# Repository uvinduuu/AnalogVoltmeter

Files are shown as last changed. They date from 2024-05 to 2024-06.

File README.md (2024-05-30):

# Analog Voltmeter Project

## Overview

This repository contains the details and design files for the Analog Voltmeter project developed by Group 06 at the Department of Electronic & Telecommunication Engineering, University of Moratuwa, Sri Lanka. The project was completed in partial fulfillment of the requirements for the module EN 2091 Laboratory Practice and Projects.

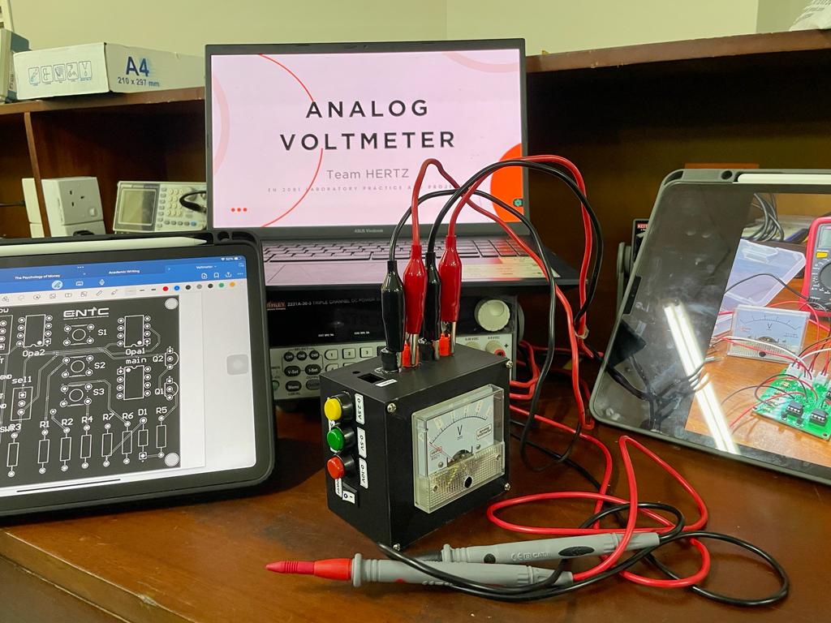
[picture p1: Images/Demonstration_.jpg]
Final Demonstration


## Group Members

- Sehara G.M.M.
- Kodikara U.S.S.
- Pathirana R.P.S.
- Gunawardhana E.R.N.H.

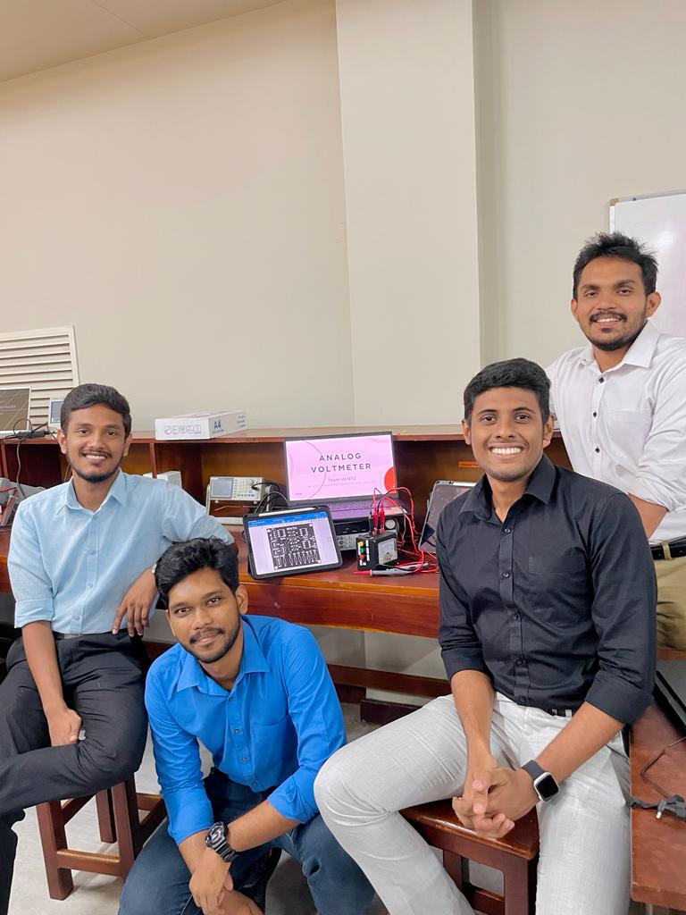
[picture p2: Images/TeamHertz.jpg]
Team


## Project Abstract

The analog voltmeter is designed to measure voltage levels in electronic circuits across three ranges: 0-2.5V, 0-5V, and 0-10V. The device uses precision analog components like resistors, capacitors, and operational amplifiers to ensure accurate voltage measurements. The design, simulation, and optimization are carried out using NI Multisim 14.2, SolidWorks for enclosure design, and Altium for PCB design.

## Contents

1. [Introduction and Functionality](#introduction-and-functionality)
2. [System Architecture](#system-architecture)
   - [Functional Block Diagram](#functional-block-diagram)
   - [Maintaining a high Input Impedance](#maintaining-a-high-input-impedance)
   - [Overload Protection](#overload-protection)
   - [Measurement Range](#measurement-range)
   - [Analog Display Customization](#analog-display-customization)
   - [Power Supply](#power-supply)
3. [Component Selection](#component-selection)
4. [PCB Design](#pcb-design)
5. [Enclosure Design](#enclosure-design)
6. [Software Simulation and Hardware Testing](#software-simulation-and-hardware-testing)
7. [Conclusion & Future Works](#conclusion--future-works)
8. [Bill of Materials](#bill-of-materials)
9. [References](#references)

## Introduction and Functionality

The primary objective is to design a high-precision voltmeter that provides accurate voltage measurements while imposing minimal impact on the circuit under test. Unlike traditional voltmeters, our project incorporates operational amplifiers (Op-Amps) to achieve high input impedance and effectively isolate the voltmeter circuit from the measured circuit.

## System Architecture

### Functional Block Diagram

The system comprises four main blocks: input, output, power supply, and amplifier. The amplifier block consists of the main amplifier and the overload protection circuit.

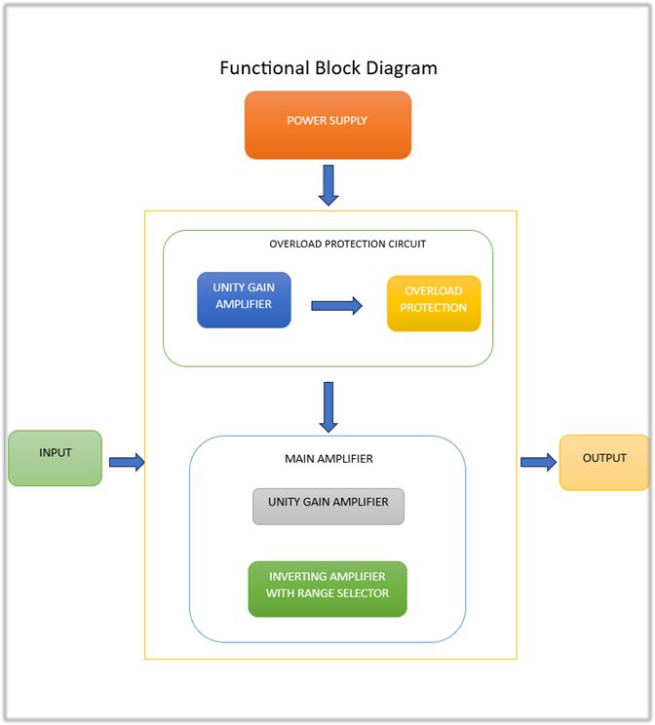
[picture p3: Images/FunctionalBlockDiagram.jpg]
Functional Block Diagram


### Maintaining a high Input Impedance

A unity gain amplifier circuit utilizing the LM358 operational amplifier is used to maintain high input impedance, ensuring accurate voltage readings.

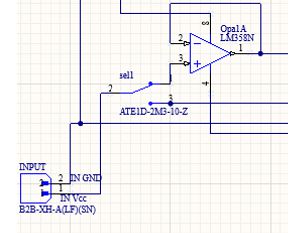
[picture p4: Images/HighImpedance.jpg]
Unity gain amplifier


### Overload Protection

An effective overload protection system using BC558 PNP transistors and a 16-volt Zener diode is implemented to protect the voltmeter from potential overload scenarios.

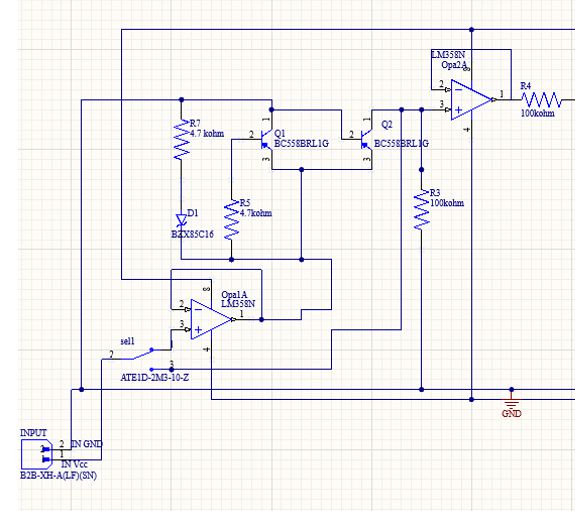
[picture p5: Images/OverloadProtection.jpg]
Overload Protection


### Measurement Range

The voltmeter can measure across three distinct ranges: 0-2.5V, 0-5V, and 0-10V, with the flexibility to select the desired range using push buttons.

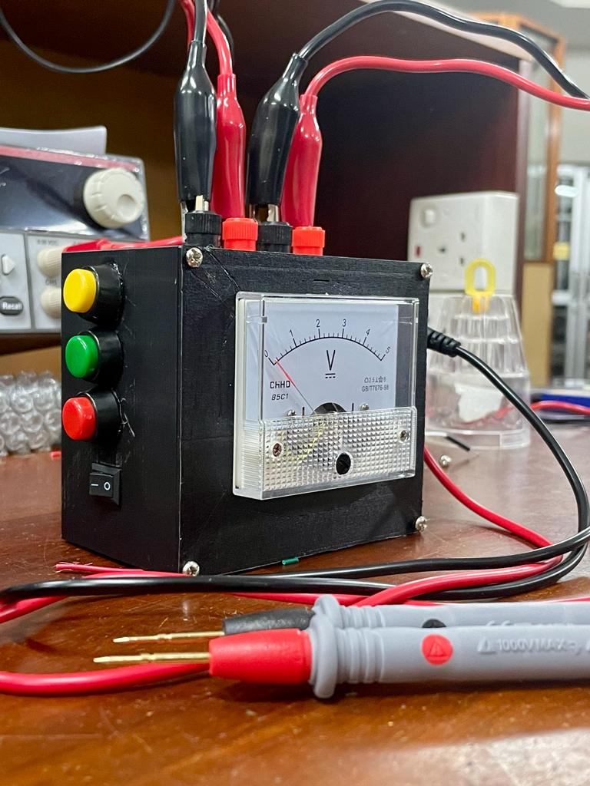
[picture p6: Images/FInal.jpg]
Final Product


### Analog Display Customization

A customized analog display featuring an analog needle is implemented for voltage measurement across three distinct ranges.

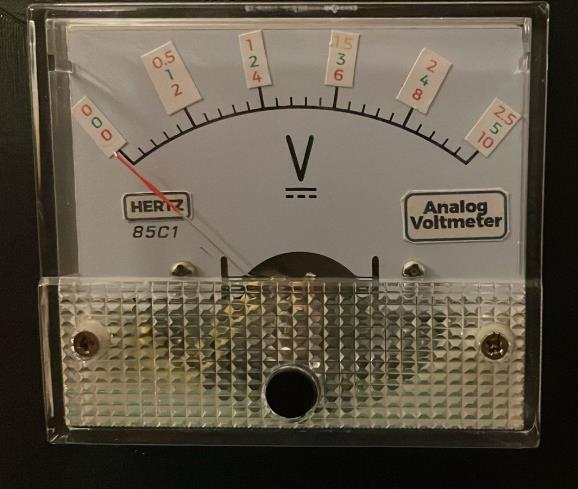
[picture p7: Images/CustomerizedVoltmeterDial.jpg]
Analog Display


### Power Supply

A dedicated power supply circuit transforms the incoming 230V AC voltage into a consistent +12V and -12V DC supply for the operational amplifiers.

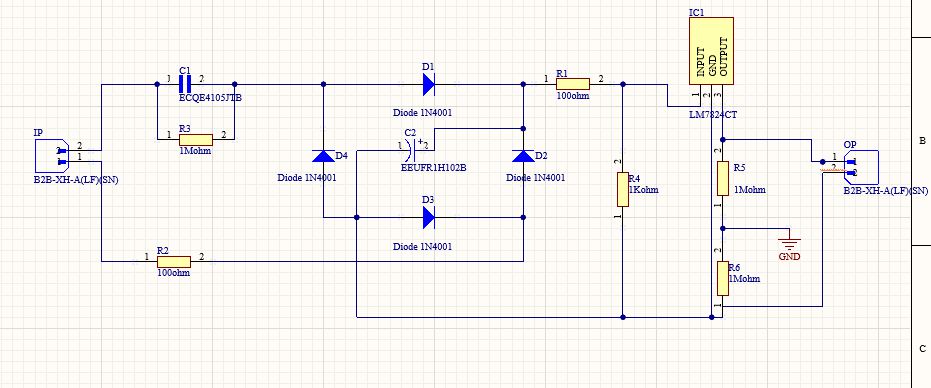
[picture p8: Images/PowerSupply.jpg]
PowerSupply


## Component Selection

- **Overload Protection**: BC558B Transistor, LM358P Op-Amp, 16V Zener diode
- **Main Amplifying Circuit**: LM358P Op-Amp, Resistors (100Kohm, 50Kohm, 200Kohm), Voltmeter Panel
- **Power Supply Circuit**: IN4001 Diodes, Capacitors, LM7824 Voltage Regulator

## PCB Design

We have designed two PCBs for the voltmeter and the power supply circuit. The PCB is designed using Altium with a compact layout to optimize performance. Design files are available in the repository.

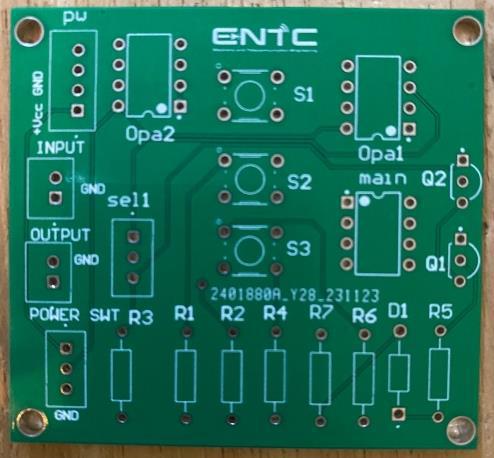
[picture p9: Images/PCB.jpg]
Voltmeter main PCB

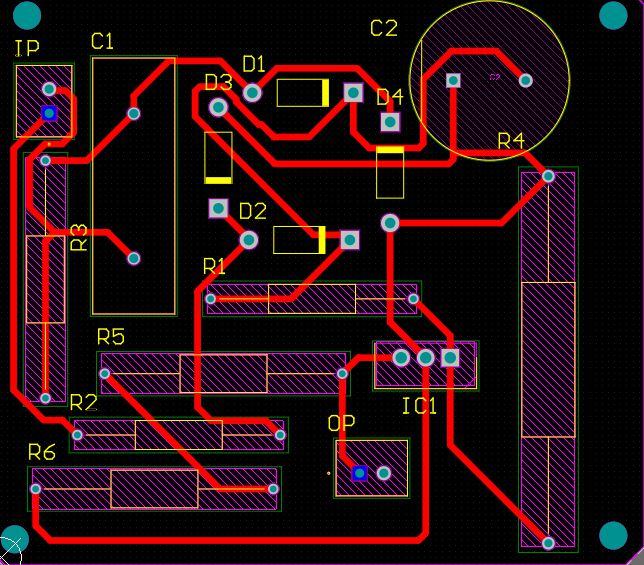
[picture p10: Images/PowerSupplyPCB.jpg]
Power Supply PCB


## Enclosure Design

The enclosure is designed using SolidWorks, ensuring user-friendly access and durability. Design files are available in the repository.

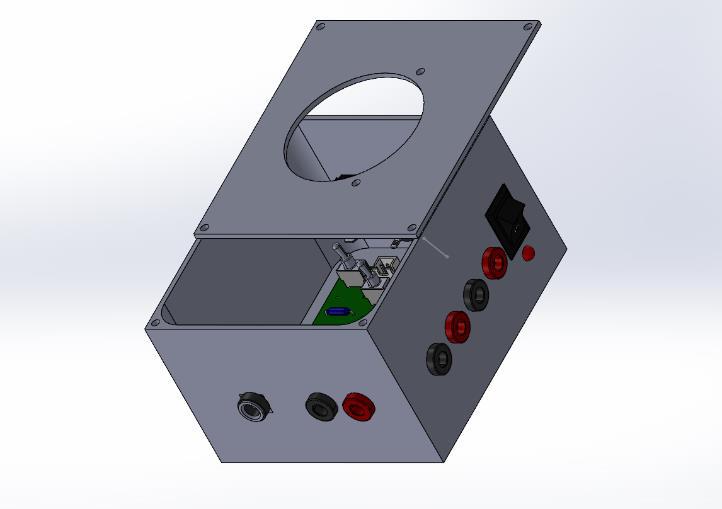
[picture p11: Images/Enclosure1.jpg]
Enclosure


## Software Simulation and Hardware Testing

Simulations were performed using Multisim software to validate the circuit design, followed by hardware implementation and testing to ensure accurate results.

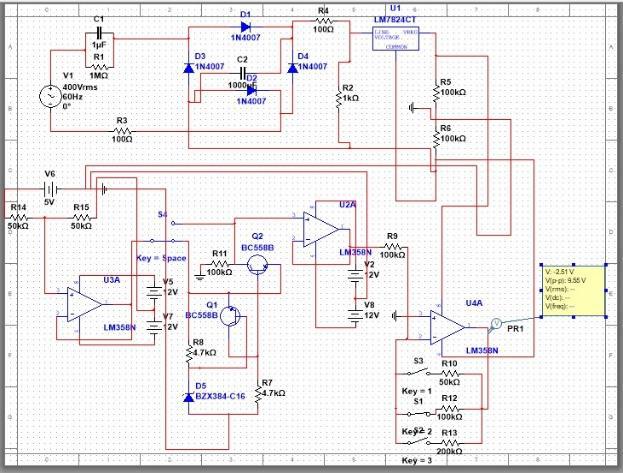
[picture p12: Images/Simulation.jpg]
Simulation

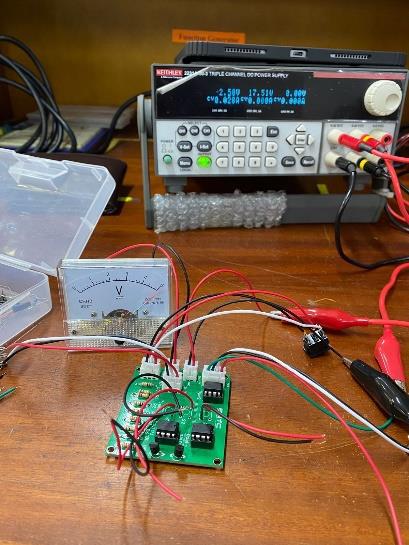
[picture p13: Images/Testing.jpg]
Testing

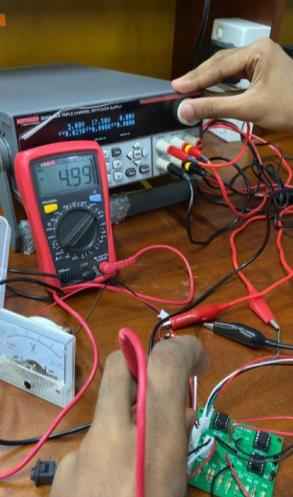
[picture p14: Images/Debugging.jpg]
Debugging


## Conclusion & Future Works

The project aims to provide a cost-effective and reliable analog voltmeter solution with emphasis on precision, durability, and ease of use. Future developments include PCB implementation for optimized power supply, boost converter integration, improved measurement parameters, and implementing a static calibration mechanism.

## Bill of Materials

| Component | Description | Quantity |
|---|---|---|
| BC558B Transistor | PNP Bipolar Junction Transistor | 2 |
| LM358P Op-Amp | Dual Operational Amplifier | 3 |
| 16V Zener Diode | Zener Diode for Voltage Regulation  | 1 |
| Resistor 100KΩ | Resistor | 2 |
| Resistor 50KΩ | Resistor | 1 |
| Resistor 200KΩ | Resistor | 1 |
| Voltmeter Panel | Analog Voltmeter Display | 1 |
| IN4001 Diode | General-Purpose Diode | 4 |
| Capacitors | Various values for filtering | Multiple |
| LM7824 Voltage Regulator| 24V Voltage Regulator | 1 |

---

A detailed bill of materials is provided in the report, listing all components used in the project.

## References

1. [Overvoltage Protection Circuit](https://circuitdigest.com/electronic-circuits/overvoltage-protection-circuit) (no date) Circuit Digest - Electronics Engineering News, Latest Products, Articles and Projects.
2. [Alldatasheet.com (no date) BC558 Datasheet(PDF) – semtech corporation](https://www.alldatasheet.com/datasheet-pdf/pdf/42388/SEMTECH/BC558.html), ALLDATASHEET.COM - Electronic Parts Datasheet Search.
3. [Alldatasheet.com (no date b) LM358 PDF, LM358 description, LM358 datasheet, LM358 View](https://pdf1.alldatasheet.com/datasheet-pdf/view/1648891/TI/LM358.html), ALLDATASHEET.
4. [Storr, W. (2022) Inverting operational amplifier - the inverting op-amp](https://www.electronics-tutorials.ws/opamp/opamp_2.html), Basic Electronics Tutorials.
5. [How to connect a PNP transistor in a circuit](https://www.learningaboutelectronics.com/Articles/How-to-connect-a-pnp-transistor-in-a-circuit.php) (No date).

---
## Contact

For any clarifications or inquiries please feel free to contact me at uvindukodikara@gmail.com

---

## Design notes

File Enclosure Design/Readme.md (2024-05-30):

# Enclosure Design for Analog Voltmeter Project

## Overview

We have designed a custom enclosure using SolidWorks for the analog voltmeter project. This enclosure is designed to house the circuit components and provide user-friendly access to connectors and controls.

### Enclosure Specifications

- **Dimensions**: The enclosure measures 10cm x 9cm.
- **User-Friendly Design**: Special attention was given to usability and accessibility during the design process.
- **Power Supply**: The enclosure includes:
  - 4 banana connectors for laboratory power supply connection.
  - 1 barrel jack connector for 24V power supply connection. Users can choose either power source.
- **Probe Connections**: Two banana connectors are provided for connecting the probes.
- **Switches**: The enclosure features:
  - A power switch.
  - A separate switch for enabling overload protection.
- **Push Buttons**: There are 3 push buttons for range selection.

## Enclosure Design

The enclosure is designed to ensure ease of use and protection for the circuit components. It provides clear access to connectors and switches, enhancing user interaction and functionality.

### SolidWorks Design

The enclosure was created using SolidWorks, focusing on precise dimensions and ergonomic usability. Detailed attention was given to integrate all necessary components effectively.

Enclosure Design
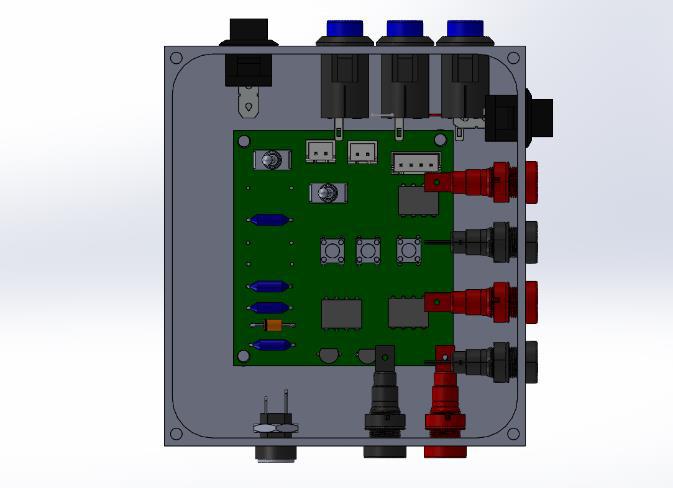
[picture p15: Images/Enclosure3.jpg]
Enclosure Design


*Figures : Enclosure design rendered using SolidWorks.*

## Future Developments

Future iterations of the enclosure may include enhancements for improved durability, aesthetics, and functionality based on user feedback and project requirements.

## Assembly Instructions

1. **Component Installation**: Carefully install the circuit components inside the enclosure.
2. **Connector Connections**: Connect the banana connectors and barrel jack as described.
3. **Switch and Button Placement**: Mount the power switch, overload protection switch, and range selection buttons in their designated positions.

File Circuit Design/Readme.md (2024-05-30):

### 1. Initial Circuit Sketch
- Create a detailed sketch of the circuit using LTSpice with the basic inverting and non inverting amplifiing circuits we learned in operational amplifier circuits. Then simulated them using NI Multisim.
- List all components and their connections as we have to select 3 ranges in the amplifier and the overload protection.

### 2. Circuit Simulation Using NI Multisim
- Model the circuit in NI Multisim.
- Conduct two separate simulations:
  - Voltmeter Simulation: Verify voltage measurement and calibration.
  - Power Supply Simulation: Verify stability and output characteristics.
- Combine simulations into a single setup to ensure compatibility and functionality.
  
Full Simulation

*Figure : Simulation with Power Supply*

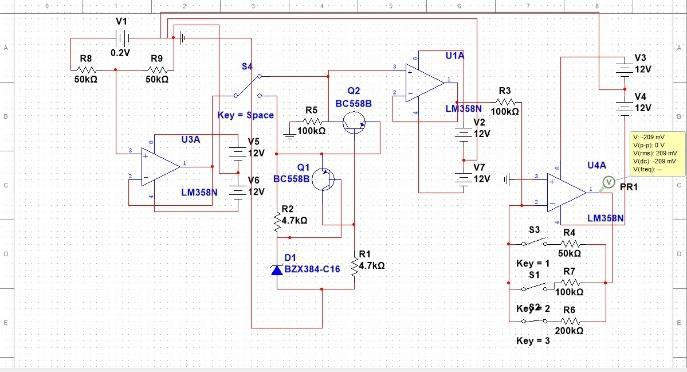
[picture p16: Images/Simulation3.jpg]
Simulation Range 1


*Figure : Simulation in 0-2.5V Range*

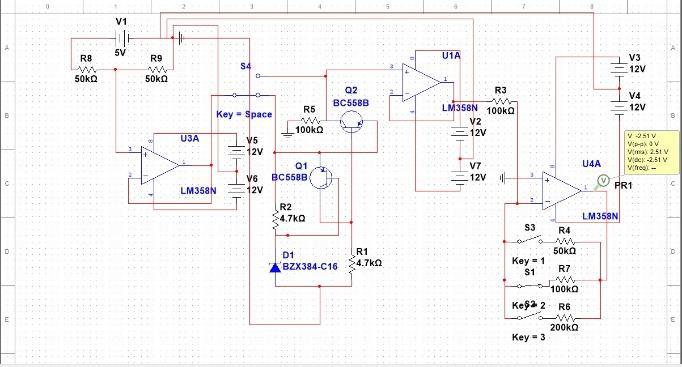
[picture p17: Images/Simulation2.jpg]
Simulation Range 2


*Figure : Simulation in 0-5V Range*

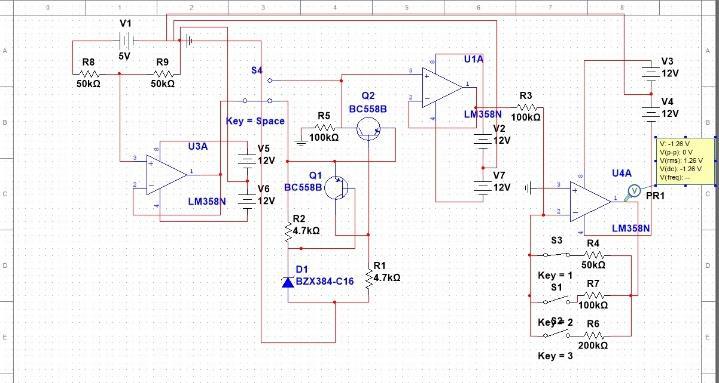
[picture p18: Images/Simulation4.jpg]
Simulation Range 3


*Figure : Simulation in 0-10V Range*

### 3. Prototyping on Breadboard
- Assemble the circuit on a breadboard.
- Debug and resolve any issues.
- Calibrate the circuit for optimal performance.

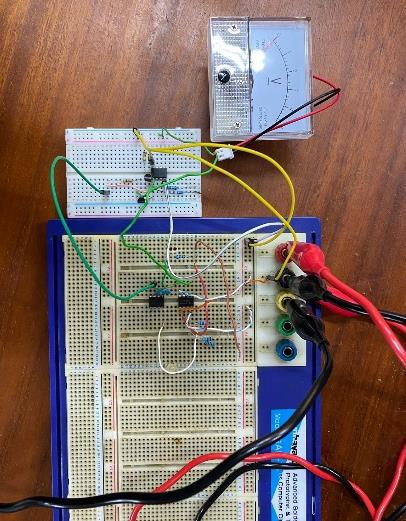
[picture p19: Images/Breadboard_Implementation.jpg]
Breadboard Implementation


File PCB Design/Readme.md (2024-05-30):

# PCB Overview

This project involves the design, construction, and testing of an analog voltmeter circuit along with its associated power supply. The circuit was initially prototyped on a breadboard, then implemented on custom PCBs. The power supply circuit is designed as a single-layer PCB, while the range amplifier PCB is a two-layer design.

## PCB Details

### Power Supply Circuit

- **PCB Configuration**: The power supply circuit is designed on a single-layer PCB.
- **Manufacturing Details**: The power supply PCB was manufactured locally in Sri Lanka, leveraging a domestic PCB printing shop.
- **Component Type**: All components used in the power supply circuit are through-hole components.

### Range Amplifier PCB

- **PCB Configuration**: The range amplifier PCB is designed on a two-layer PCB.
- **Manufacturing Details**: PCB was fabricated through JLCPCB, utilizing their online PCB manufacturing service.
- **Component Type**: All components used in the range amplifier circuit are through-hole components.

## Testing and Verification

The circuit was extensively simulated across different voltage ranges (0-2.5V, 0-5V, and 0-10V) to ensure functionality and accuracy. After successful soldering, the circuit was tested using an oscilloscope and other necessary equipment to verify functionality and performance.

## Future Developments

As a beginner-level project, this prototype utilizes through-hole components. Future plans involve redesigning the PCBs using surface-mount device (SMD) components to achieve a more compact and efficient design.

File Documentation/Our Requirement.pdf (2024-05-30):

## 1. Introduction

The Analog Voltmeter Project combines traditional engineering with modern usability. Analog

voltmeters, iconic instruments of electrical measurement, bridge the past and present. This project

aims to revive and update these devices, blending classic charm with contemporary accuracy. By

crafting smart circuitry and sleek design, we aim to preserve analog's essence while meeting

today's precision needs. This introduction highlights our mission to merge tradition and innovation

in voltage measurement.

## 2. Technical Specifications

1. Measurement Range: Design the voltmeter to accurately measure a voltage range of

100 mV – 10 V, by dividing this whole range into 2 or 3 sub-ranges and adjustable with

selector switches.

2. Accuracy: Achieve a high level of accuracy, with a tolerance of ±1% or better, to ensure

reliable voltage readings.

3. Sensitivity: Incorporate a sensitivity control mechanism to allow users to adjust the

instrument's responsiveness to varying input voltages.

4. Analog Display: Implement a clear and easy-to-read analog display using a robust and

calibrated analog needle or pointer.

5. Input Impedance: Maintain a high input impedance to prevent voltage drop when

connected to circuits under test.

6. Signal Conditioning: Employ appropriate signal conditioning to reduce noise interference

and enhance measurement accuracy.

7. Overload Protection: Integrate built-in protection to safeguard the voltmeter from

potential damage due to excessive voltage inputs.

8. Power Source: Provide a reliable and stable power source, ensuring consistent and

accurate meter operation.

9. Calibration Mechanism: Design a calibration mechanism or adjustment points to fine-

tune the voltmeter's accuracy when needed.

## 3. Additional Notes

- All the circuits must be simulated using software (Ex- LT Spice, Multisim, PLECS etc.)

before the implementation.

- All circuits should be tested on the breadboard and reviewed by the assigned supervisor

before moving further.

- Circuits must be designed using professional EDA software (Altium Designer, OrCAD)
- Schematics should be verified and evaluated by the assigned supervisor.
- Design for manufacturability should be considered when designing the PCB Complete set

of design and manufacturing documents Schematics, Layout, 3D file Gerber files,

Assembly files BoM must be generated and properly documented.

- Students are encouraged to procure components from international component distributors

(Mouser, DigiKey, Arrow Electronics, LCSC).

- Students are encouraged to get the PCBs manufactured from international PCB

manufacturers (JLCPCB, PCBway).

- Main functionality of the project must be achieved with basic electronic components such

as resistors, capacitors, inductors, diodes, transistors and other analog integrated circuits.

- Using any other pre-built programmable ICs are prohibited.
- Microcontrollers can be only used for user interface operation.
- Enclosure design must be done using a professional software (Solidworks).
- Enclosure and 3D model of the circuit must be assembled and inspected before

manufacturing. 3D printing, Laser cutting, and Sheet metal bending can be used to

manufacture the enclosure.

- Student are encouraged to consider the 3D model and PCB co-design (design in parallel by

taking their integration into consideration) when designing.

- Final implementation of the project needs to done in a PCB.
- Follow provided “General guidelines”.

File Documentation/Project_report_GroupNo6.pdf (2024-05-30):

Analog Voltmeter | Group 06

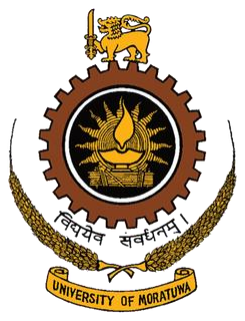
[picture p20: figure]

Department of Electronic & Telecommunication Engineering

University of Moratuwa, Sri Lanka.

# Analog Voltmeter

Group Members:

210583B Sehara G.M.M.

210293K Kodikara U.S.S.

210451U Pathirana R.P.S.

210200C Gunawardhana E.R.N.H.

Submitted in partial fulfillment of the requirements for the module.

EN 2091 Laboratory Practice and Projects

06/12/2023

## Abstract

This report provides an overview of the design process for an analog voltmeter aimed at measuring voltage levels in electronic circuits. The voltmeter is designed to operate within 3 ranges; 0-2.5V, 0-5V and 0-10V, offering reliable voltage readings for various applications. The methodology involves the utilization of analog components such as resistors, capacitors, and operational amplifiers (OPAMPs) to construct different functional blocks within the voltmeter circuit.

The core design incorporates precision analog components to ensure accurate voltage measurements. NI Multisim 14.2 software is employed for circuit design and simulation, allowing for thorough testing and optimization of individual components. Additionally, SolidWorks software is utilized for the creation of a robust and aesthetically pleasing enclosure to house the analog voltmeter, ensuring durability and user-friendly design.

Furthermore, Altium software is employed for the printed circuit board (PCB) design, enabling the efficient layout of components for optimal performance. The project aims to provide a cost-effective and reliable analog voltmeter solution for electronic enthusiasts and professionals, with an emphasis on precision, durability, and ease of use.

## Contents

## 1. Introduction and Functionality

Introduction:

This analog voltmeter project aims to address the common issue of voltage drop and circuit loading encountered in conventional voltmeters. The primary objective is to design a high-precision voltmeter that provides accurate voltage measurements while imposing minimal impact on the circuit under test. Unlike traditional voltmeters that often draw current from the circuit, leading to voltage inaccuracies, our project incorporates operational amplifiers (Op-Amps) to achieve high input impedance and effectively isolate the voltmeter circuit from the measured circuit.

Functionality:

The key functionality of our analog voltmeter project focuses on achieving high input impedance to minimize the impact on the measured circuit. Traditional voltmeters often introduce voltage inaccuracies by drawing current from the circuit under test. To overcome this, Op-Amps are strategically used to create a buffer, ensuring the voltmeter draws minimal current and maintains a high input impedance. This design choice guarantees accurate and reliable voltage readings, making the voltmeter suitable for applications requiring precision without compromising the integrity of the measured circuit.

## 2. System Architecture

Functional Block Diagram

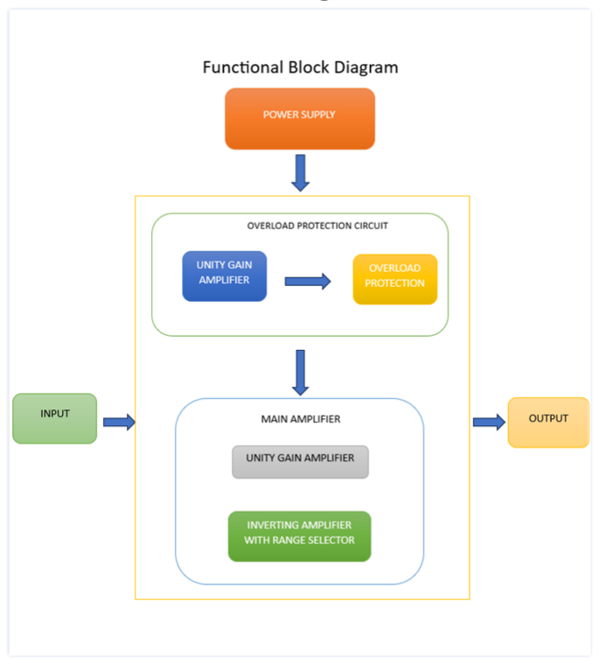
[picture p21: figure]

The system comprises four main blocks: input, output, power supply, and amplifier. Input is facilitated through two probes, and the customized voltmeter panel serves as the output.

There are few power supply options are available, including using a 230V to 24V power adapter, direct power connection, utilizing a dual channel 12V power supply, or employing a 24V power supply designed in-house.

The amplifier block consists of two main parts: the main amplifier and the overload protection circuit. The main amplifier features an inverting amplifier with three ranges and
a range selector.

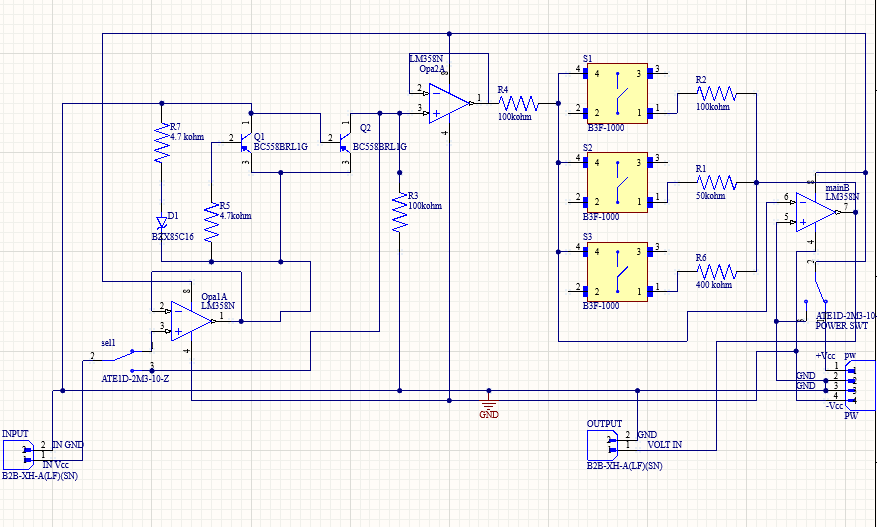
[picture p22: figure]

Schematic Diagram

Maintaining a high Input Impedance

At the initiation of our probe, we integrated a unity gain amplifier circuit utilizing the LM358 operational amplifier. This strategic incorporation serves the purpose of isolating the circuit from the voltmeter, thereby maintaining an exceptionally high input impedance. The utilization of the LM358 op-amp is particularly advantageous, as it draws a negligible current from the circuit.

The unity gain amplifier, inherent in the LM358 op-amp, ensures that the output voltage mirrors the input voltage, allowing us to safely channel the voltage into our circuit. This design choice mitigates the risk of voltage drop associated with the internal resistance of the voltmeter. By virtue of this configuration, our system adeptly prevents any compromise in voltage integrity, facilitating accurate and reliable measurements without distortion.

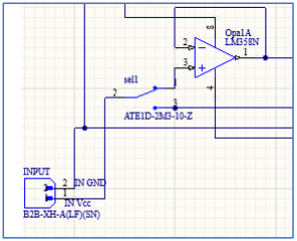
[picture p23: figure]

Overload Protection Mechanism

To safeguard our voltmeter from potential mishaps caused by inadvertent overload scenarios, we've implemented an effective overload protection system. This system is comprised of two BC558 PNP transistors and a 16-volt Zener diode carefully chosen to align with the specific requirements of our setup.

The selection of a 16-volt Zener diode is deliberate, considering the input voltages of 12V. It ensures that the Zener voltage is above 12V, safeguarding against potential harm to the voltmeter needle, while not exceeding 20V to maintain optimal functionality within safe limits (keeping in mind that the LM358 op-amp can handle up to 36V).

In operation, when the voltage is below the preset level, the base terminal of Q2 is high, causing it to turn off. With Q2 in the off state, the base terminal of Q1 is low, allowing current to flow through it. However, when the voltage surpasses the predetermined value, the Zener diode begins conducting, connecting the base of Q2 to ground and activating Q2. As a result, the base terminal of Q1 becomes high, causing Q1 to turn on and behave as an open switch. This, in turn, prevents the flow of current through Q1, effectively protecting the load from excessive voltage and ensuring the safety of the voltmeter in overload situations.

Inserted between the overload protection circuit and the three-range amplification system, a crucial unity gain amplifier serves to isolate these two sections. This isolation prevents current draw from the load, averting any potential voltage drop issues. The unity gain amplifier acts as a buffer, ensuring stable voltage levels and safeguarding the accuracy of voltage measurements throughout the entire system.

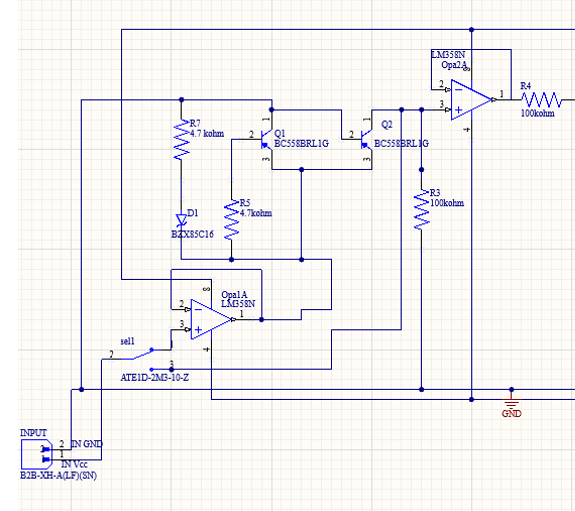
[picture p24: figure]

Overload Protection Circuit

Measurement Range

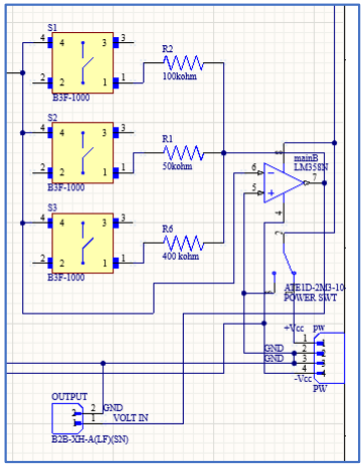
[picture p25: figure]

The voltmeter has been primarily designed to measure across three distinct ranges: 0-2.5V, 0-5V, and 0-10V. This design enables the measurement of minimum voltages of 100mV, 200mV, and 400mV, respectively. To achieve these varying ranges, three different resistors are employed in conjunction with three inverting op-amp mechanisms. Additionally, the user is provided with the flexibility to select the desired range through the incorporation of three push buttons.

Analog Display Customization

In our design, we have implemented a customized analog display featuring an analog needle equipped with a pointer, specifically tailored for the measurement of voltages across three distinct ranges. Each range on the analog display is meticulously divided into five segments, providing clear and precise readings.

To ensure accuracy and adaptability, an in-built screw mechanism has been incorporated, allowing for the calibration of the needle based on initial conditions. This feature ensures that the analog needle aligns accurately with the voltage scale, guaranteeing reliable and calibrated voltage measurements across the selected ranges.

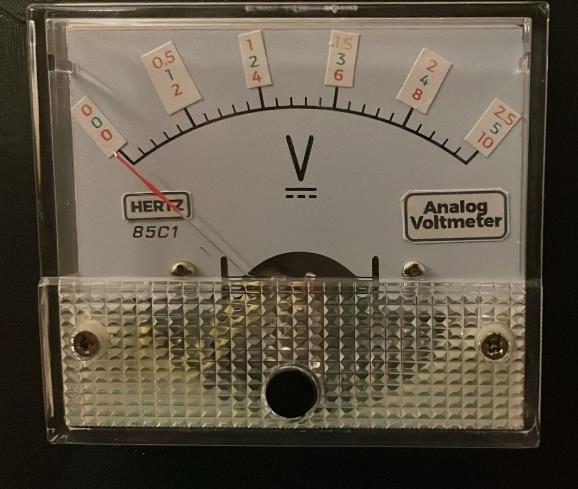
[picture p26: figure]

Power Supply

To ensure reliable and stable operation of the meter, a dedicated power supply circuit has been developed. This circuit transforms the incoming 230V AC voltage into a consistent +12V and -12V DC supply for all three operational amplifiers. The design incorporates a bridge with four IN4001 diodes, a 24V voltage regulator, as well as capacitors and resistors to optimize performance.

Additionally, flexibility has been integrated into the power options for the voltmeter. It can be powered externally using a wall power adapter with a 230V AC to 24V DC output. Moreover, for laboratory applications, the voltmeter can be powered by a dual channel 12V power supply. The latter option features four connector ports to facilitate easy and convenient connection of probes to the power supply. This dual-powered approach enhances the adaptability and versatility of the voltmeter in different usage scenarios.

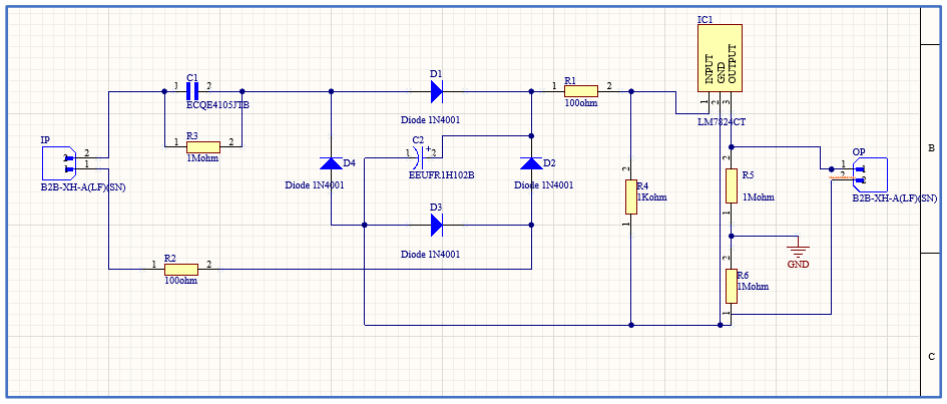
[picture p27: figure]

Power Supply Circuit Schematic

## 3. Component Selection

1. Overload Protection
- BC558B Transistor – Used to cutoff the input volage when input voltage become higher than 13V to protect the main amplifier circuit. It has high cutoff voltage and low saturation current.
- LM358P – Used this op-amp to isolate the main circuit from input and overload protection circuit.
- 16V Zener diode - We use 16V Zener diode to set the threshold through the transistors. So, we can cut the voltages higher than the 13V and protect the main op-amp and the voltmeter panel.

2. M ain Amplifying Circuit
- LM358P – Used as the non-inverting amplifier to amply the input voltages according to the dc voltage.
- 100Kohm,50Kohm and 200Kohm - These resistors are used for range selection. When we measure the 10V range. We selected 50Kohm for 5V range and we used 200Kohm range for 2.5V range.
- Voltmeter Panel – We use voltmeter panel to indicate what is the value of measuring voltage.
3. Power Supply Circuit
1. IN4001 Diodes – To rectify the input AC voltage and get the DC output voltage.
2. 2W, 400v 1uf capacitor – To reduce the voltage 230V rms to 34V rms. Also, we use 2W capacitors because the high current can be gone through the circuit and prevent the components from high current.
3. 2W, 50V 1000uf capacitor - To reduce the ripple voltage of the DC output.
4. LM7824 Voltage Regulator – Regulate the voltage to the 24V DC output.
5. 2W, 1Mohm – Prevent the diode, voltage regulator and other connected components from surge current.

## Calculations

Amplifier gain

Input impedance of the main op-amp amplifier – 100Kohm

Output impedance of the main op-amp – 50Kohm

Threshold Voltage of overload protection – 13V

0-10V Range

Vo = Vin (Rf/R)

A = Rf/R

= 50kohm/100kohm

= 0.5

0-5V Range

A = Rf/R

= 100Kohm/100Kohm

= 1

0-2.5V Range

A = Rf/R

= 200Kohm/100Kohm

= 2

## 4. PCB Design

For the analog voltmeter, we designed a compact 54 x 58mm printed circuit board (PCB) using Altium. The PCB, a two-layered structure, was manufactured in China and subsequently shipped to our location.

Traces of the lines are 0.254mm width. The drill hole size in the PCB is 3mm. We placed the components in such a way to overcome the complexity in the routing and thermal heating issues.

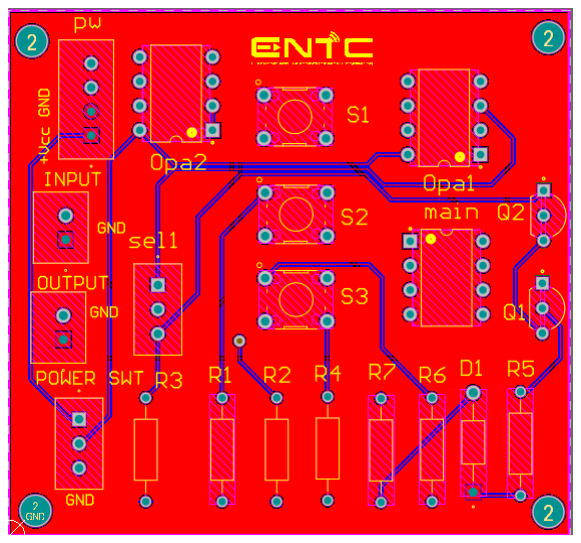
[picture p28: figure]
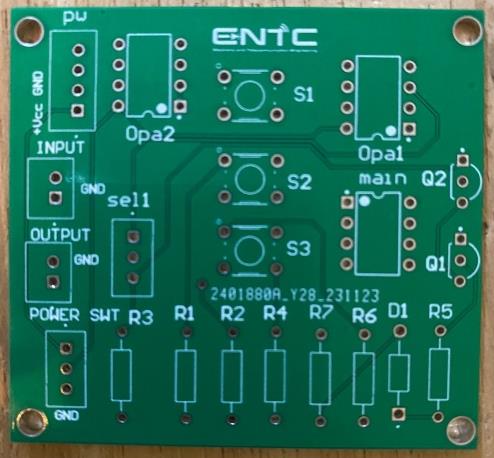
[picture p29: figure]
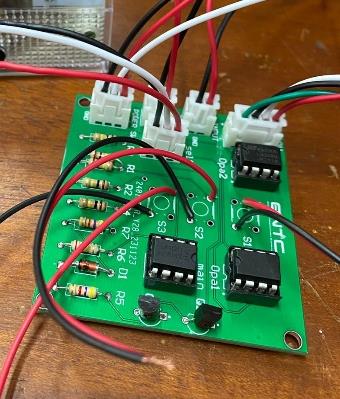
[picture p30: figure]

PCB Design | PCB | Soldered PCB

We also designed a separate power supply to power up the circuit. For it, we designed a compact 60 x 65mm printed circuit board (PCB) using Altium. The PCB, a single-layered structure.

Traces of the lines are 1.2mm width. The drill hole size in the PCB is 3mm. We placed the components in such a way to overcome the complexity in the routing and thermal heating issues.

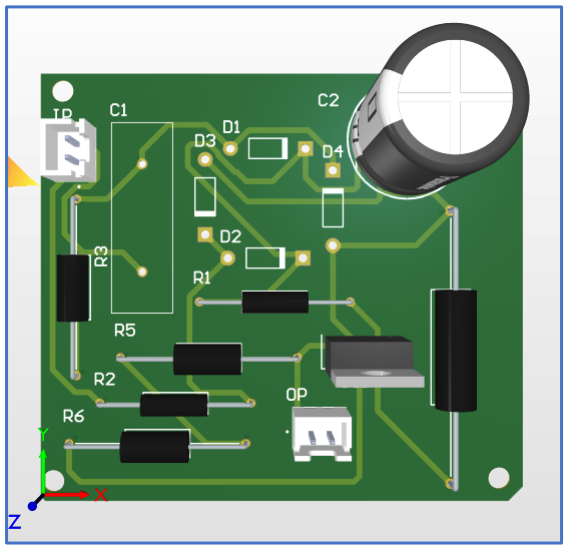
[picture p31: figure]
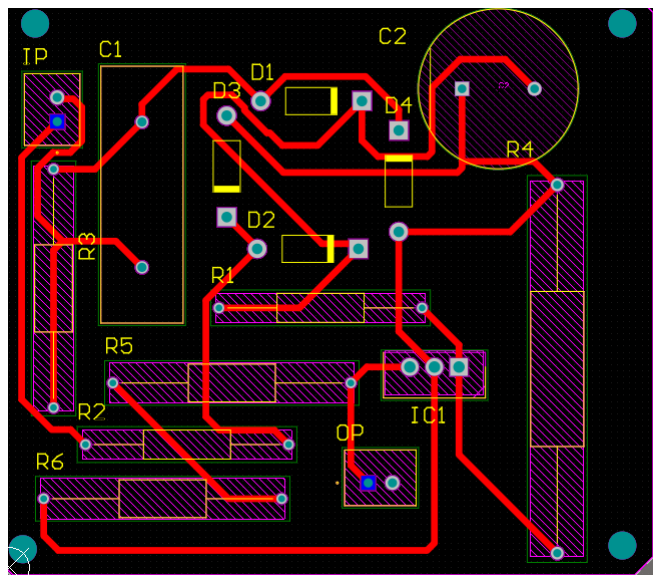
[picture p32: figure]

Power supply PCB 3D view | Power Supply PCB Design

PCB Design Files – https://dms.uom.lk/s/xP8RYKjXwsNPgjf

## 5. Enclosure Design

We have designed an enclosure using SolidWorks. The enclosure measures 10cm x 9cm and is designed to be user-friendly. During the design process, we paid special attention to the power supply. The enclosure has 4 banana connectors to connect to the laboratory power supply and a barrel jack connector to connect to the 24V power supply. The user can use either one of them.

We have also used two banana connectors to connect the two probes. Additionally, you have added a power switch and a separate switch to enable overload protection. The enclosure has 3 push buttons for range selection.

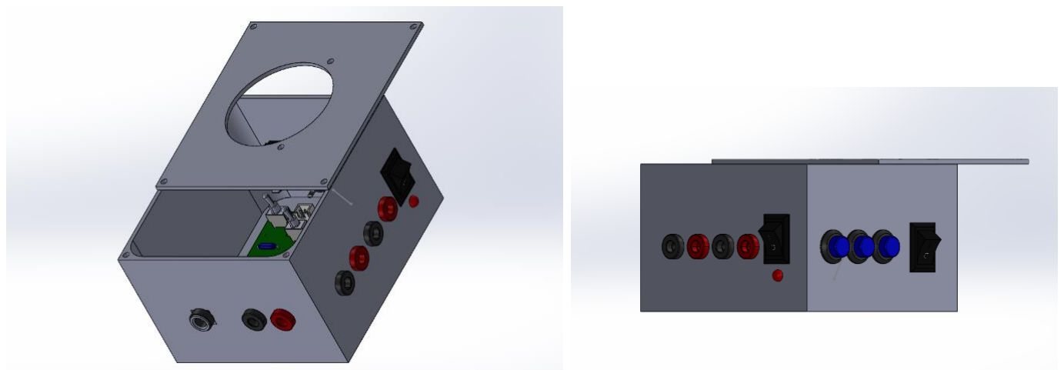
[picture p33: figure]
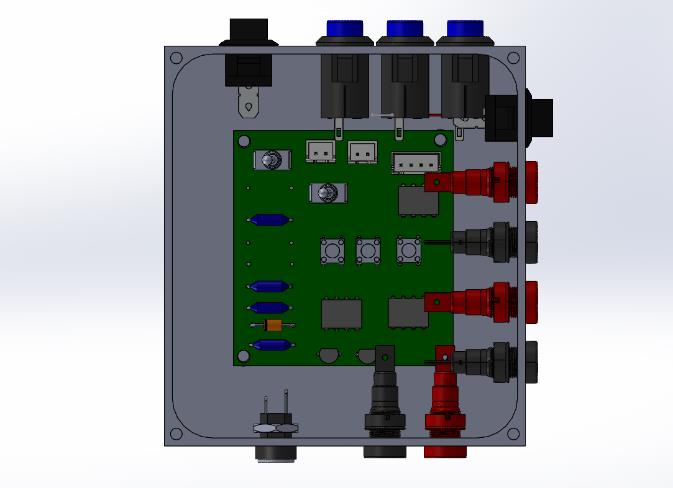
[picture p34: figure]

Enclosure Design

Enclosure Design Files - https://dms.uom.lk/s/JL3cXNGJY5aBqZH

## 6. Software Simulation and Hardware Testing

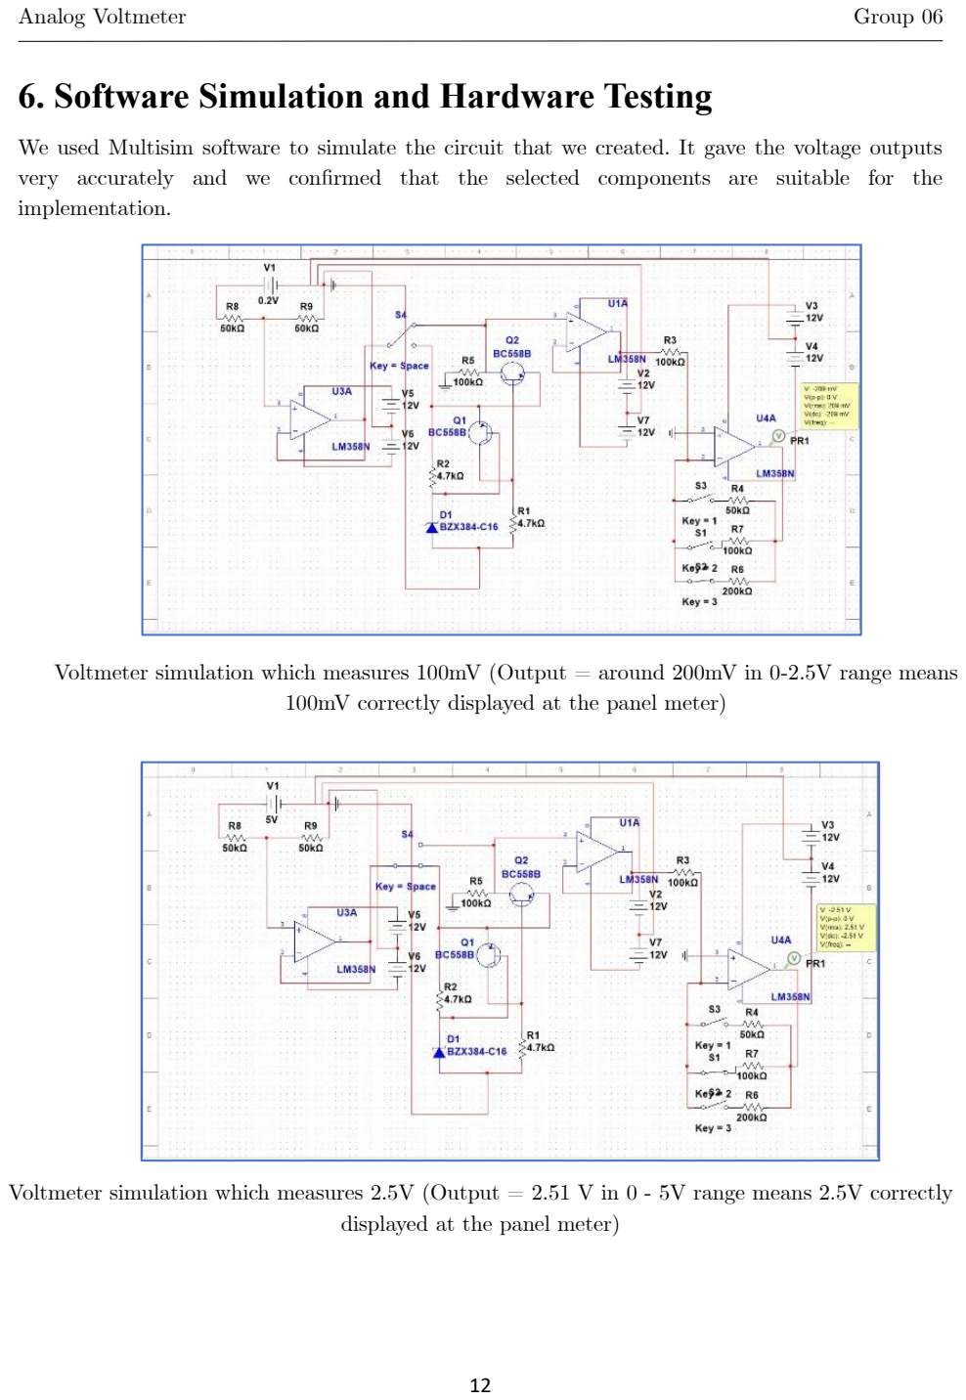
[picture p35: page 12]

We used Multisim software to simulate the circuit that we created. It gave the voltage outputs very accurately and we confirmed that the selected components are suitable for the implementation.

Voltmeter simulation which measures 100mV (Output = around 200mV in 0-2.5V range means 100mV correctly displayed at the panel meter)

Voltmeter simulation which measures 2.5V (Output = 2.51 V in 0 - 5V range means 2.5V correctly displayed at the panel meter)

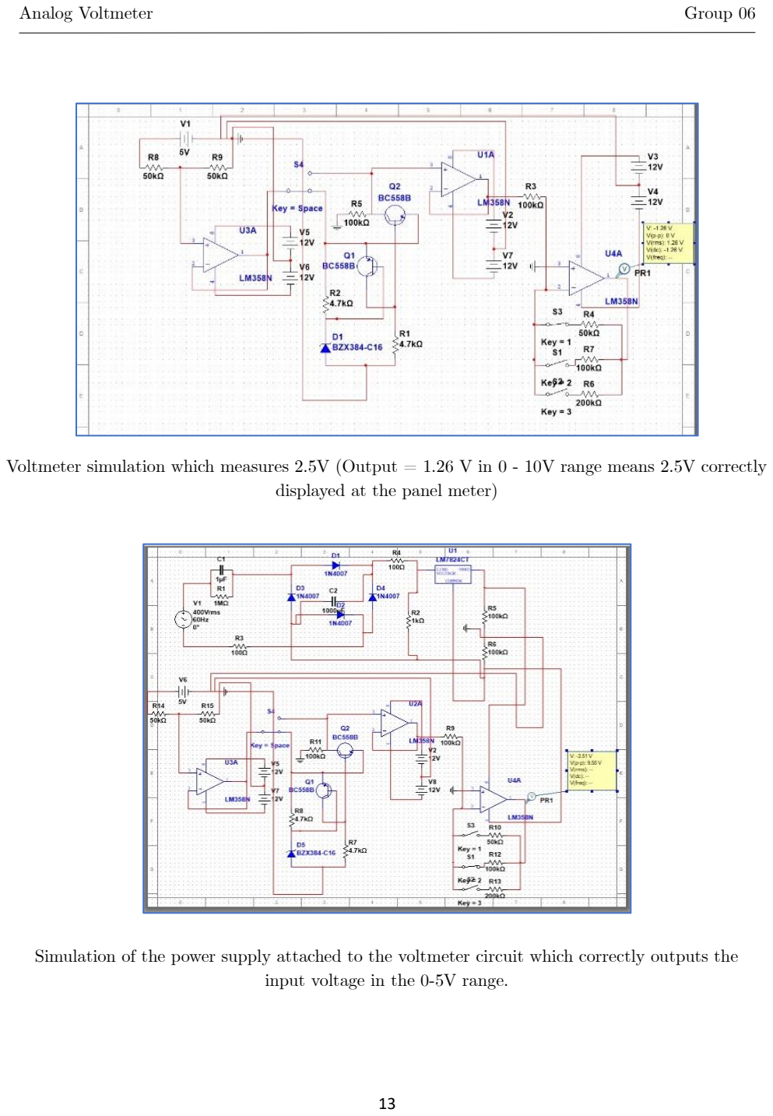
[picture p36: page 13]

Voltmeter simulation which measures 2.5V (Output = 1.26 V in 0 - 10V range means 2.5V correctly displayed at the panel meter)

Simulation of the power supply attached to the voltmeter circuit which correctly outputs the input voltage in the 0-5V range.

First, we implemented the circuit on the bread board and calibrated the components until getting successful results. Then we designed the PCB and did a PCB testing using the multimeter by checking the output voltage. Finally, we have attached every component to our enclosure and did a testing and got successful results.

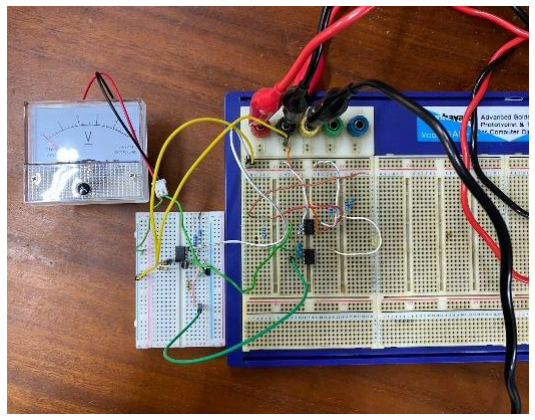
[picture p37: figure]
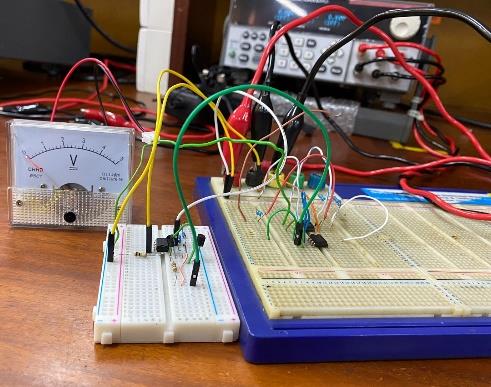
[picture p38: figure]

Breadboard Implementation


PCB Testing


## 7. Conclusion and Future Works

### Results

0-10V Range | 0-5V Range | 0-2.5V Range

### Future Developments

### 1. PCB Implementation for the Optimized Power Supply

- Finalize the in-house power supply for the voltmeter by developing a printed circuit board (PCB) for the designed power supply to enhance reliability and streamline the manufacturing process.

### 2. Boost Converter Integration

- Implement a boost converter to elevate the DC voltage, enabling the use of rechargeable batteries. This enhancement promotes increased mobility and compactness of the voltmeter.

### 3. Improved Measurement Parameters

- Enhance the voltmeter's functionality by lowering the minimum voltage measurement to 50mV.
- Achieve a tolerance level of +/-0.5% to ensure precision and accuracy in voltage readings.

### 4. Implementing a Static calibration mechanism

- Utilizing potentiometers as feedback resistors and varying the potentiometers’ resistance until the correct gain is achieved. This process will enhance the accuracy of the voltmeter under different conditions.
Voltage | Reading | Error
0 | 0 | 0%
0.5 | 0.5 | 0%
1 | 0.99 | 1%
1.5 | 1.5 | 0%
2 | 2.01 | 0.5%
2.5 | 2.5 | 0%
Voltage | Reading | Error
0 | 0 | 0%
2 | 1.95 | 2.5%
4 | 3.9 | 2.5%
6 | 5.9 | 1.67%
8 | 7.8 | 2.5%
10 | 9.85 | 1.5%
Voltage | Reading | Error
0 | 0 | 0%
1 | 1 | 0%
2 | 1.98 | 1%
3 | 2.95 | 1.67%
4 | 3.95 | 1.25%
5 | 5 | 0%

### Conclusion and Discussion

This project fulfills almost all the requirements, but there are some constraints we couldn’t overcome. The main problem we faced was providing power to the op-amps. After some research, we were able to find a solution and design our own power supply, which can directly plug into the wall and the voltmeter. However, we couldn’t print the PCB, so we had to use a dual-channel power supply in the laboratory.

Another drawback of our design is that when we turn on the overload protection circuit, we can’t measure voltages below 500mV. Therefore, we have to use a separate switch to turn ON/OFF the overload protection circuit when measuring 100mV. To overcome this issue, we would need to change the transistors, but we couldn’t find another model that fulfills our needs.

Despite these challenges, as we were able to achieve the required accuracy of +/-1% and a minimum measurement of 100mV, overall, we have designed a successful project for an analog voltmeter with high impedance.

## 8. Bill of Materials

Component | Quantity | Price
LM358B IC | 8 | 80.00
BC558B | 3 | 30.00
Resisters (100Kohm, 50Kohm, 200Kohm, 4.7Kohm) 0.25W | 12 | 20.00
16V Zener Diode 1W | 2 | 10.00
Analog Voltmeter panel | 1 | 550.00
Mount Wire clips (two way and four way) | 10 | 180.00
8 pin IC base | 4 | 20.00
Banana Socket | 6 | 180.00
Multimeter probes | 2 | 225.00
Push buttons | 3 | 105.00
PCB Printing | 5 | 6000.00
Enclosure Printing 3D | 1 | 4800.00

## 9. Contribution of Group Members

210583B | Sehara G.M.M. | - Enclosure Design and Assembling
210293K | Kodikara U.S.S. | - Circuit Building, Breadboard Implementation
210451U | Pathirana R.P.S. | - PCB Design and Testing
210200C | Gunawardhana E.R.N.H. | - Power Management, Soldering

## 10. References

1. Overvoltage Protection Circuit (no date) Circuit Digest - Electronics Engineering News, Latest Products, Articles and Projects. Available at: https://circuitdigest.com/electronic-circuits/overvoltage-protection-circuit (https://circuitdigest.com/electronic-circuits/overvoltage-protection-circuit)
2. Alldatasheet.com (no date) BC558 Datasheet(PDF) – semtech corporation, ALLDATASHEET.COM - Electronic Parts Datasheet Search. Available at: https://www.alldatasheet.com/datasheet-pdf/pdf/42388/SEMTECH/BC558.html
3. Alldatasheet.com (no date b) LM358 PDF, LM358 description, LM358 datasheet, LM358 View ::: Alldatasheet :::, ALLDATASHEET. Available at: https://pdf1.alldatasheet.com/datasheet-pdf/view/1648891/TI/LM358.html
4. Storr, W. (2022) Inverting operational amplifier - the inverting op-amp, Basic Electronics Tutorials. Available at: https://www.electronics-tutorials.ws/opamp/opamp_2.html
(No date) How to connect a PNP transistor in a circuit. Available at: https://www.learningaboutelectronics.com/Articles/How-to-connect-a-pnp-transistor-in-a-circuit.php

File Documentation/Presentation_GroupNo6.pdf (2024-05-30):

Team HERTZ; ANALOG VOLTMETER

E N 2 0 9 1 L A B O R A T O R Y P R A C T I C E A N D P R O J E C T S


# Introduction

Project Objective:
Develop a high-precision voltmeter addressing common voltage drop and circuit loading issues. Key Focus:
Ensure accurate voltage measurements while minimizing impact on the tested circuit.


# Functionality


Achieve high input impedance to minimize impact on the measured circuit in our analog voltmeter project.

# System Model


Maintaining a high Input
Impedance

Variable Measurement Range

Analog Display Customization

Overload Protection

# Schematic Diagram


# PCB Design


# Enclosure Design


# Simulation Results


# Future Works

PCB Implementation

Finalize the in-house power supply for the voltmeter by developing a printed circuit board (PCB) for the designed power supply

Boost Converter Integration

Implement a boost converter to elevate the DC voltage, enabling the use of rechargeable batteries. This enhancement promotes
increased mobility and
compactness of the voltmeter

Improved Measurement
Parameters

Enhance the voltmeter's
functionality by lowering the minimum voltage measurement to 50mV.
Achieve a tolerance level of +/-0.5% to ensure precision and accuracy in voltage readings.

# Conclusion and Discussion

Overall, successful project for a high-impedance analog voltmeter.

Project fulfills most requirements, but faced some constraints.
Main challenge: Power supply for op-amps.

Solution: Designed custom power supply for direct wall and voltmeter connection.

PCB printing issues led to using a dual-channel power supply in the lab.

Overload protection circuit limitation: Cannot measure below 500mV.

Solution: Added a separate switch for ON/OFF control when measuring 100mV.

Transistor change required to fully overcome the limitation, but suitable model not found.

Achieved required accuracy of +/-1% and minimum measurement of 100mV.

# Individual Contributions

210583B Sehara G.M.M.
210293K Kodikara U.S.S.

210451U Pathirana R.P.S.
210200C Gunawardhana E.R.N.H.

## - Enclosure Design and Assembling - Circuit Building, Breadboard Implementation - PCB Design and Testing - Power Management, Soldering


# Team HERTZ

# Thank You

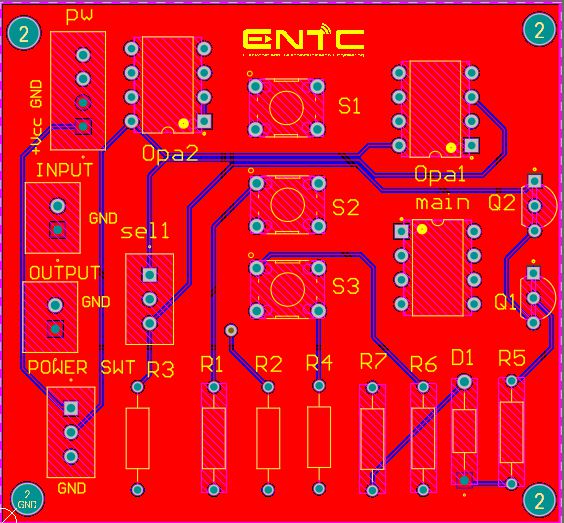
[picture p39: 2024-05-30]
Images/Layer.jpg

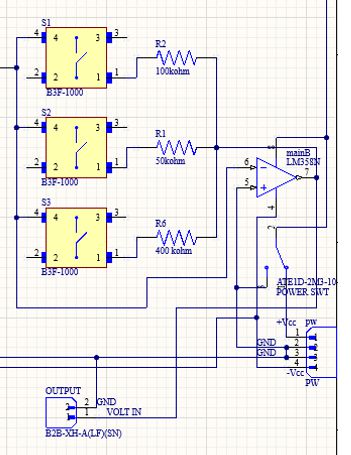
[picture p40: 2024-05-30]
Images/Amplifiers.jpg

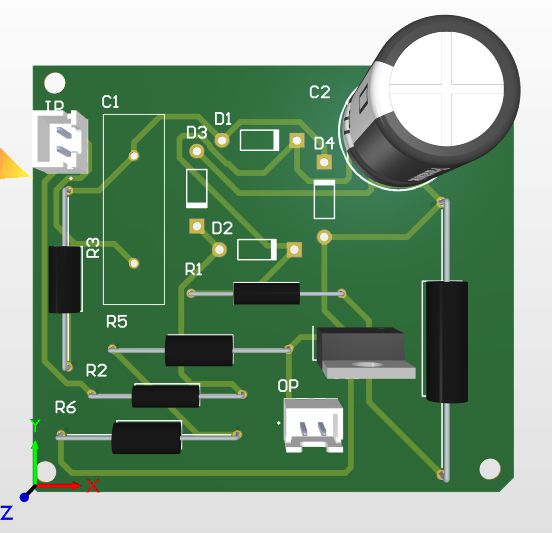
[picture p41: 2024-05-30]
Images/3DView.jpg

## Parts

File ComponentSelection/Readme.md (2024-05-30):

## Overview
This project involves the design of an analog voltmeter with overload protection, using various electronic components to ensure accurate measurement and circuit protection.

## Circuit Components

### 1. Overload Protection Circuit
- **BC558B Transistor**
  - Used to cutoff the input voltage when it exceeds 13V, protecting the main amplifier circuit.
  - Features high cutoff voltage and low saturation current.
- **LM358P**
  - Op-amp used to isolate the main circuit from the input and overload protection circuit.
- **16V Zener Diode**
  - Used to set the threshold voltage through the transistors, cutting off voltages higher than 13V to protect the main op-amp and the voltmeter panel.

### 2. Main Amplifying Circuit
- **LM358P**
  - Used as the non-inverting amplifier to amplify the input voltages according to the DC voltage.
- **Resistors (100KΩ, 50KΩ, 200KΩ)**
  - Used for range selection:
    - 100KΩ for general resistance.
    - 50KΩ for measuring the 10V range.
    - 200KΩ for measuring the 2.5V range.
- **Voltmeter Panel**
  - Indicates the measured voltage value.

### 3. Power Supply Circuit
1. **IN4001 Diodes**
   - Rectify the input AC voltage to obtain DC output voltage.
2. **2W, 400V 1μF Capacitor**
   - Reduces the voltage from 230V RMS to 34V RMS.
   - The 2W rating is to handle high current and protect components from high current.
3. **2W, 50V 1000μF Capacitor**
   - Reduces the ripple voltage of the DC output.
4. **LM7824 Voltage Regulator**
   - Regulates the voltage to a 24V DC output.
5. **2W, 1MΩ Resistor**
   - Prevents surge current from damaging the diode, voltage regulator, and other connected components.

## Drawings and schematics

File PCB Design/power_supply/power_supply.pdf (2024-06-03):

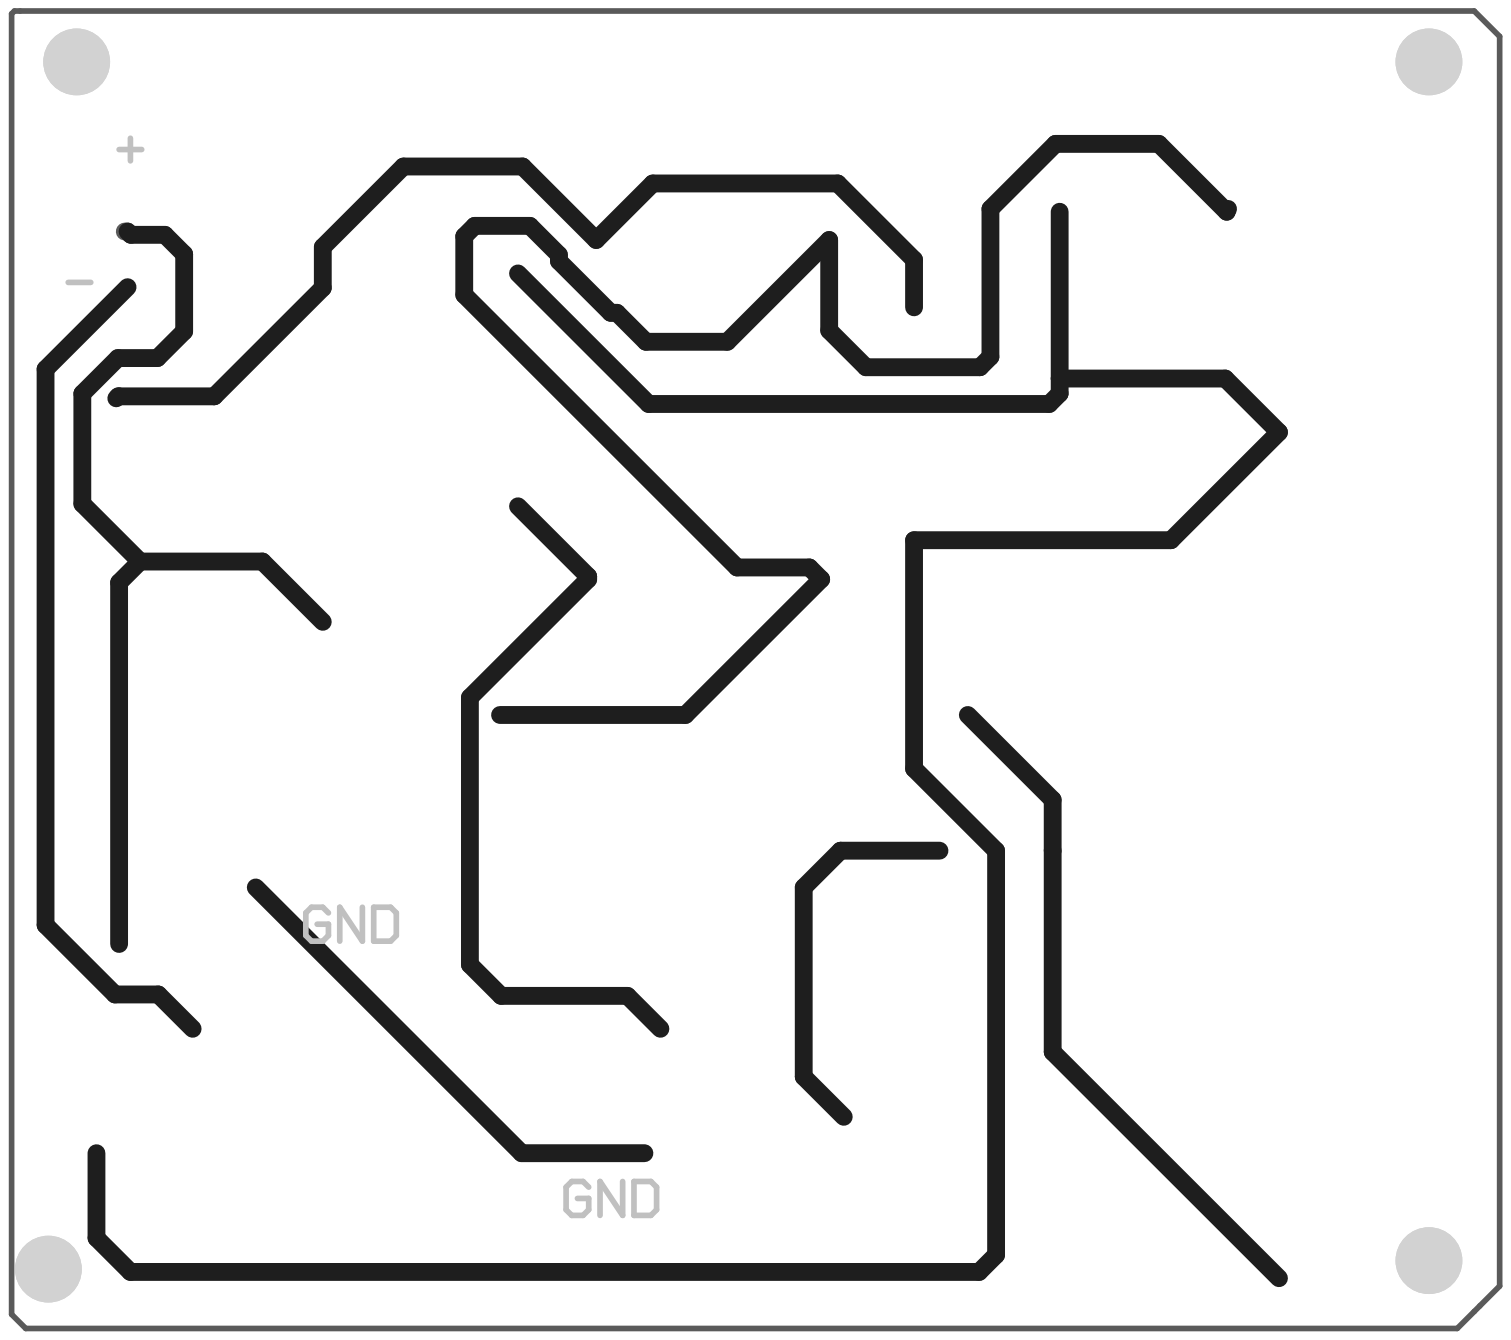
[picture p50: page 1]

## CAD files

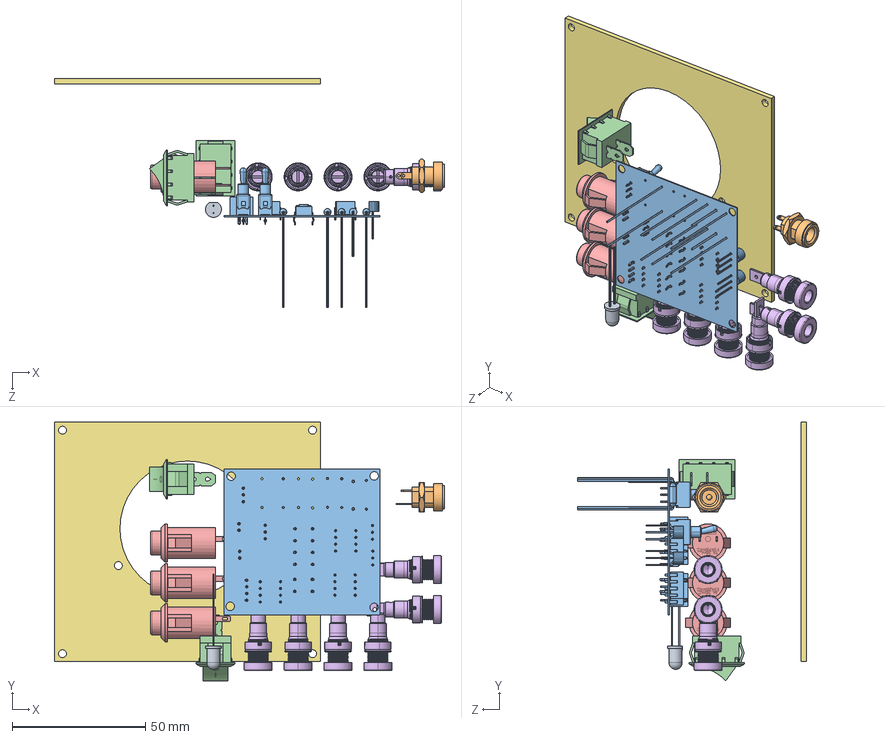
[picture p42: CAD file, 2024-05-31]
Enclosure Design/Assem1.SLDASM
146.6 x 97.2 x 86.1 mm
Lid New
Female, Banana Plug x 6
Push Switch Button (12mm) B x 3
RockerSwitch x 2
PCB1
DJ Jack 2,1mm panel mount
LED 5mm

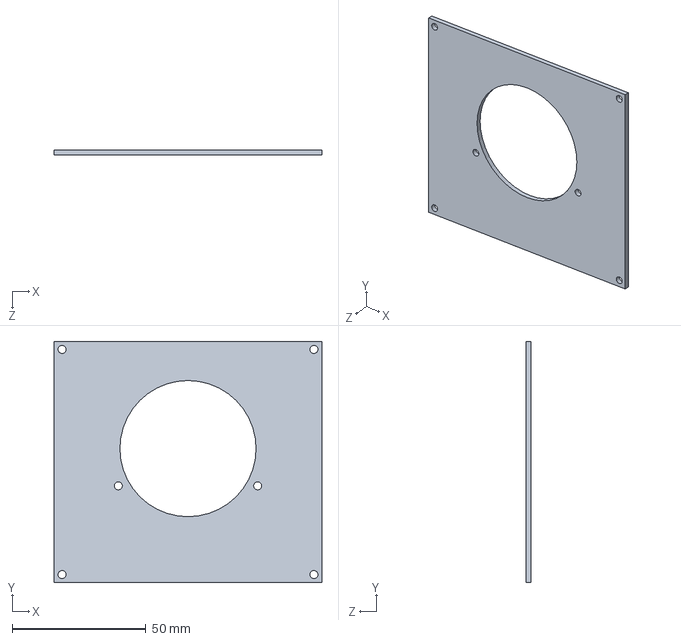
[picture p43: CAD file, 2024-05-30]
Enclosure Design/Lid New.SLDPRT
100.0 x 90.0 x 2.00 mm

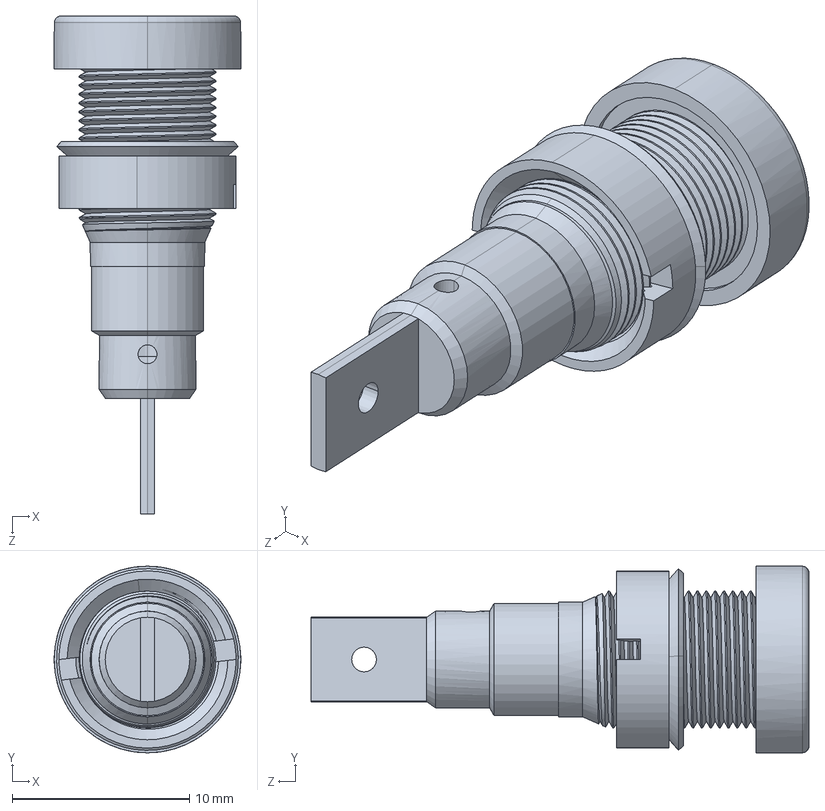
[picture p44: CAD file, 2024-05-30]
Enclosure Design/Female, Banana Plug.SLDPRT
10.5 x 10.5 x 28.1 mm

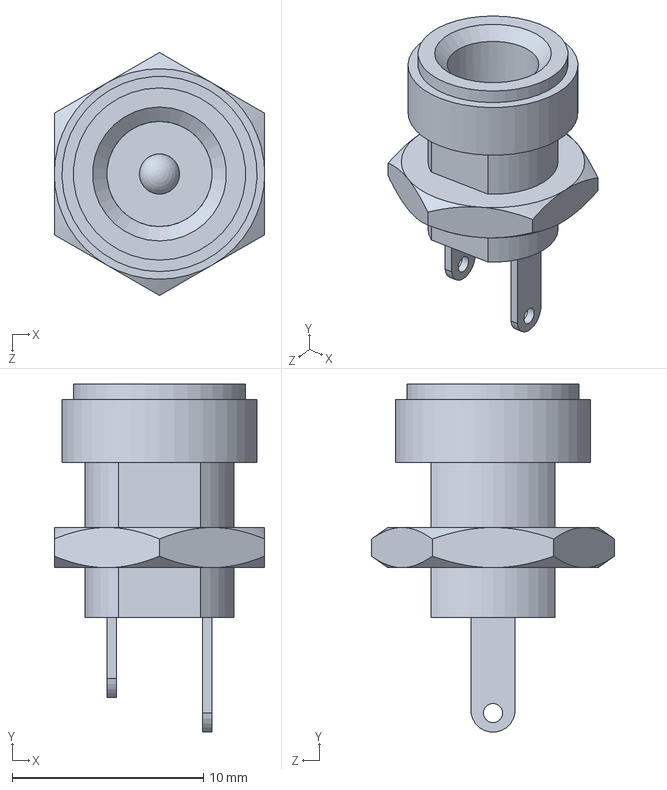
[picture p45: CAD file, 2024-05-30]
Enclosure Design/DJ Jack 2,1mm panel mount.SLDPRT
11.0 x 18.2 x 12.7 mm

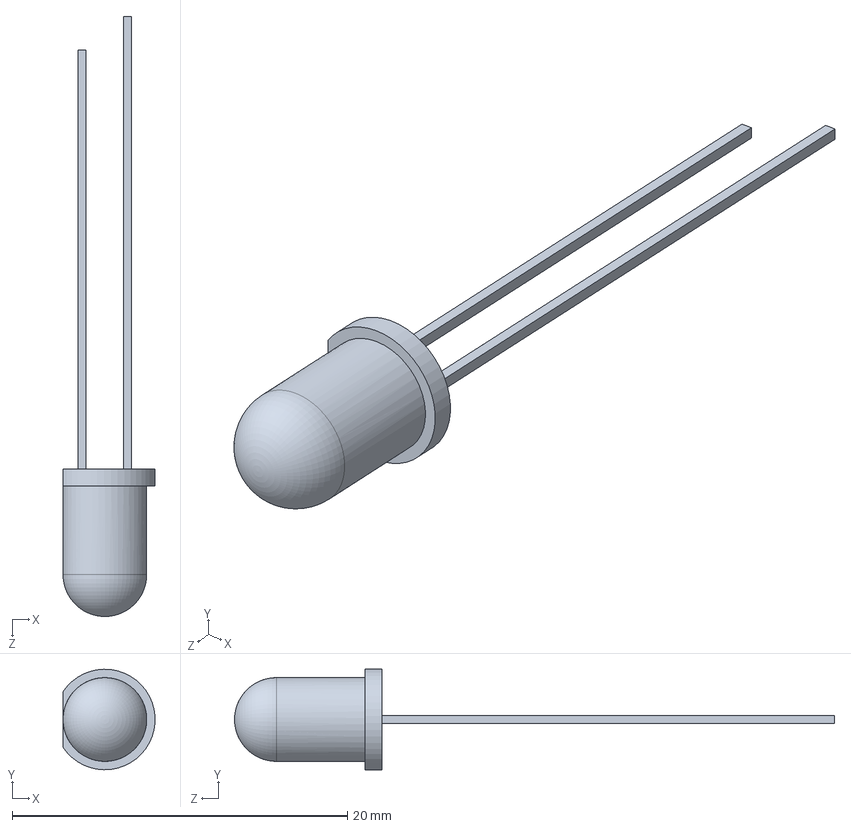
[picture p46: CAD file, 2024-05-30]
Enclosure Design/LED 5mm.SLDPRT
5.49 x 6.00 x 35.8 mm

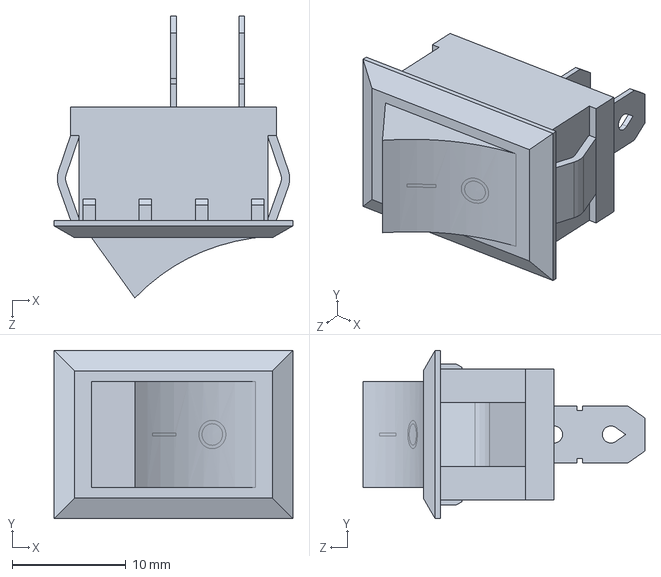
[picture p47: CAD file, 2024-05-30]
Enclosure Design/RockerSwitch.SLDPRT
21.0 x 14.8 x 24.8 mm

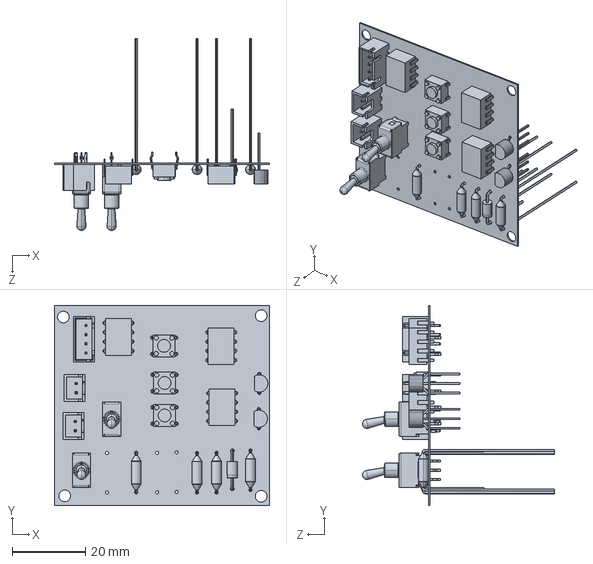
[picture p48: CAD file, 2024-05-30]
Enclosure Design/PCB1.SLDPRT
58.8 x 54.7 x 52.5 mm

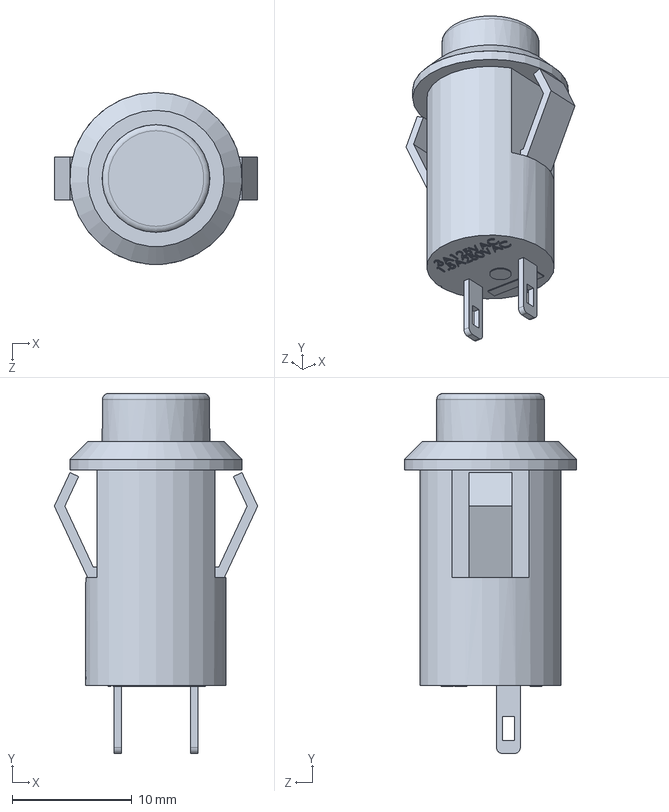
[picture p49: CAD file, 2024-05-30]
Enclosure Design/Push Switch Button (12mm) B.SLDPRT
17.0 x 30.1 x 14.4 mm
